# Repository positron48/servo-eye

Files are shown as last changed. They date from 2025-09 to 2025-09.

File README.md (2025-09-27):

# Eye Controller — ESP8266 Web‑Controlled Dual Servo

Control two hobby servos (yaw and pitch) from a responsive web UI hosted directly on an ESP8266 (Wemos D1 Mini). The firmware embeds the UI, exposes a small HTTP API, and persists settings so the device comes back exactly as you left it after power cycles.

## Contents
- [Overview](#overview)
- [Features](#features)
- [Hardware](#hardware)
- [Mounting Options](#mounting-options)
- [Quickstart](#quickstart)
- [Build and flash](#build-and-flash)
- [Web UI](#web-ui)
- [HTTP API](#http-api)
- [Servo setup and calibration](#servo-setup-and-calibration)
- [Create custom animations](#create-custom-animations)
- [Troubleshooting](#troubleshooting)
- [Technical details](#technical-details)
- [Build system (HTML → C++)](#build-system-html--c)
- [Project structure](#project-structure)
- [License](#license)
- [Support](#support)

## Overview
Eye Controller turns an ESP8266 into a self‑contained access point with a built‑in web interface to position two servos and play simple animations. It is ideal for animatronics like an eyeball that can look around with smooth motion.

<p align="center">
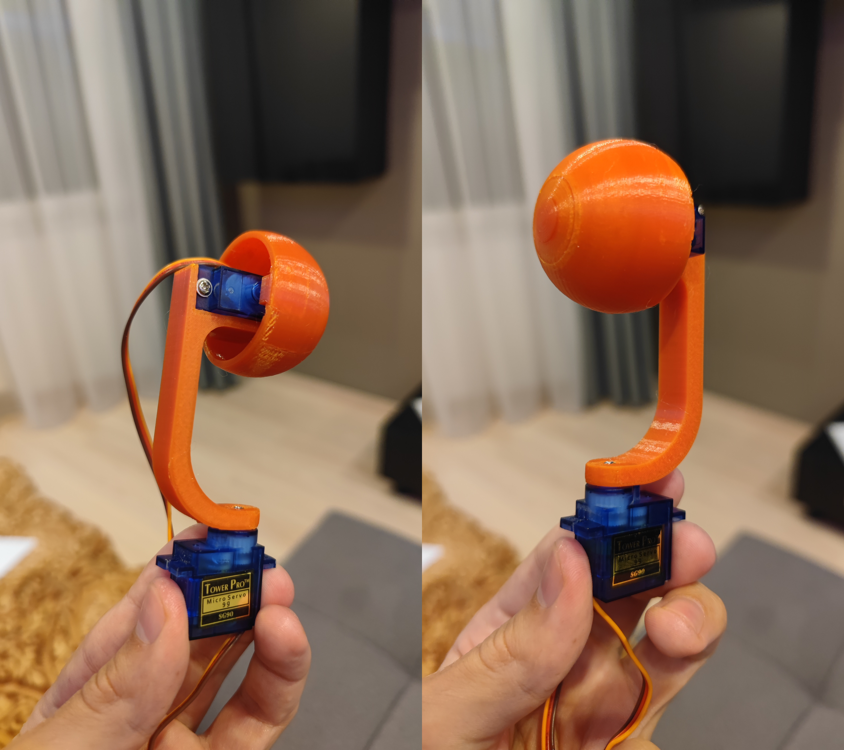
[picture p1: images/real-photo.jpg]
Real device photo
  
  <br/>
  <em>Real build of the Eye Controller in action</em>
  
</p>

## Features
- Wi‑Fi access point with a built‑in, responsive web UI
- Real‑time control for yaw and pitch
- Preset animations with adjustable speed and looping
- Settings saved to EEPROM and restored on boot
- HTML UI embedded directly in firmware (no external files required)
- Automatic HTML → C++ compilation during build

## Hardware
Target: ESP8266 (Wemos D1 Mini) + two 5V hobby servos (e.g., SG90).

<p align="center">
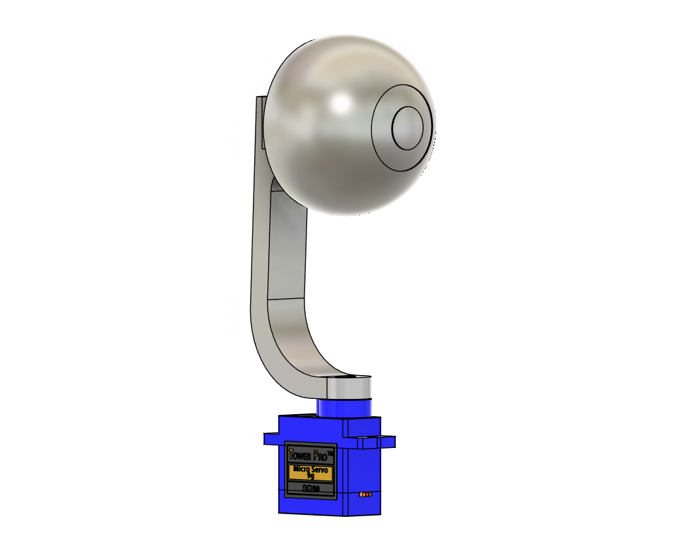
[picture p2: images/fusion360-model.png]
Fusion 360 model of the assembly
  
  <br/>
  <em>Fusion 360 model of the mechanical assembly</em>
</p>

Default connections:

```
ESP8266 (Wemos D1 Mini)    →    Servo
D1 (GPIO5)                  →    Yaw Servo signal
D2 (GPIO4)                  →    Pitch Servo signal
5V                          →    Servo power (+)
GND                         →    Shared ground
```

Recommendations:
- Power servos from a dedicated 5V source (≥2A) and tie GND with ESP8266
- Do not power servos from 3.3V pins
- Alternative pins are possible; see `ServoController.h`.

### Alternative pins
If D1 and D2 are occupied, update constants in `ServoController.h`:

```cpp
static const int YAW_PIN = D5;    // GPIO14
static const int PITCH_PIN = D6;  // GPIO12
```

Other usable pins: D5 (GPIO14), D6 (GPIO12), D7 (GPIO13). Avoid D8 (GPIO15) because it is pulled low at boot.

## Mounting Options

The project includes 3D printable mounting arms and connectors for different installation scenarios:

<p align="center">
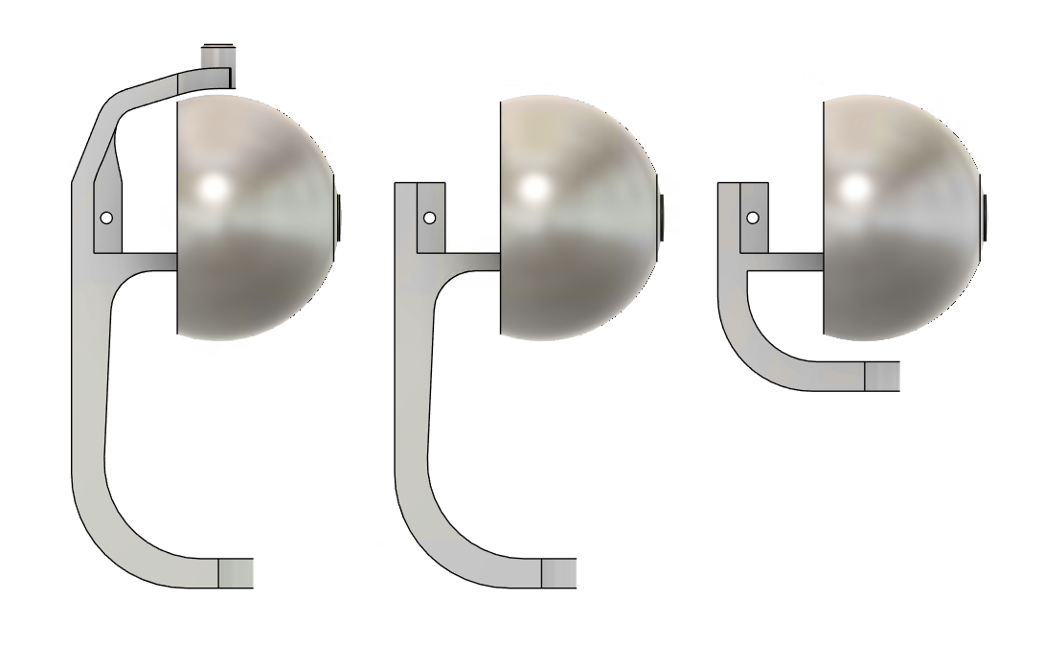
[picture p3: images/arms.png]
Mounting arm options
  
  <br/>
  <em>Three mounting arm options: long double-sided, long single-sided, and short single-sided</em>
</p>

<p align="center">
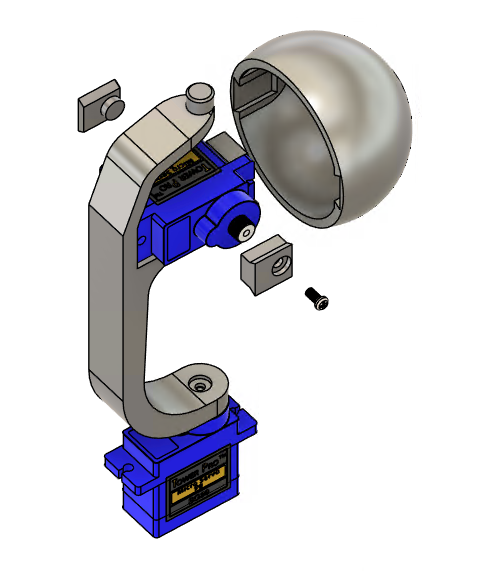
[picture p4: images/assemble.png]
Assembly example
  
  <br/>
  <em>Example assembly with mounting arms and connectors</em>
</p>

### Available STL Files
All 3D printable models are available in the [`model/`](model/) directory:

- **`arm.stl`** - Long double-sided mounting arm
- **`arm-long-one-side.stl`** - Long single-sided mounting arm  
- **`arm-short-one-side.stl`** - Short single-sided mounting arm
- **`eye.stl`** - Main eyeball housing
- **`connector1.stl`** - Servo connector #1
- **`connector2.stl`** - Servo connector #2

## Quickstart
Steps:
1) Wire two servos to D1 (yaw) and D2 (pitch), provide proper 5V power
2) Build and flash (PlatformIO):

```bash
pio run --target upload
```

3) Connect to Wi‑Fi AP: SSID `EyeController`, password `12345678`
4) Open the UI at `http://192.168.4.1` or `http://eye.local`

## Build and flash
Prerequisites:
- PlatformIO in VS Code (recommended)
- ESP8266 (Wemos D1 Mini)

Commands:

```bash
# Build and upload
pio run --target upload

# Optional: serial monitor
pio device monitor
```

The build integrates a pre‑step that compiles HTML from `web/` into C++ headers in `src/`.

## Web UI
The web UI offers:
- Canvas controller for intuitive look control with the mouse
- Yaw/Pitch sliders for precise positioning
- Preset animations with speed and loop options
- Built‑in CSV editor for custom animation sequences

<p align="center">
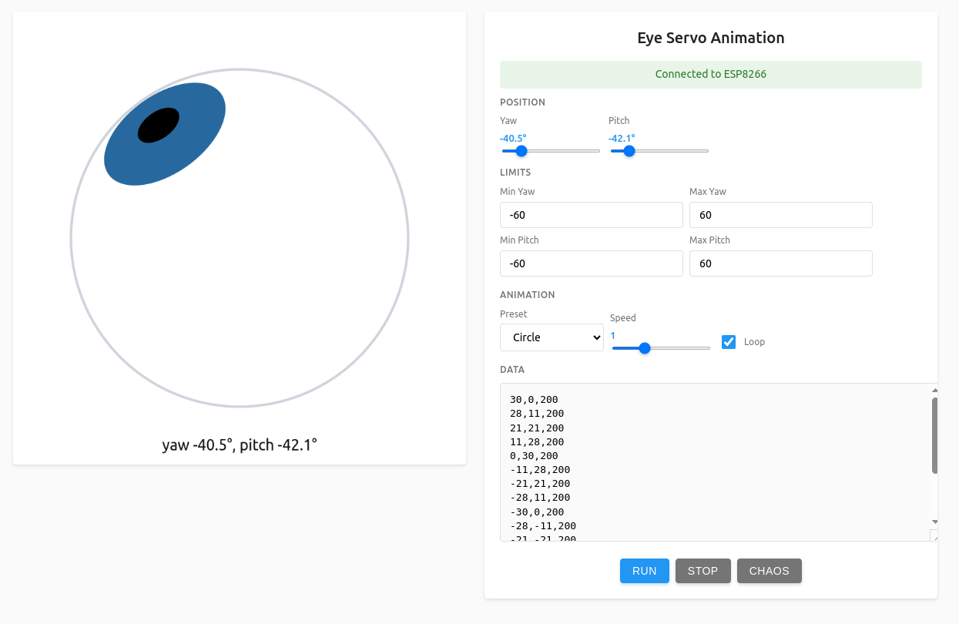
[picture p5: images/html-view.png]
Web UI screenshot
  
  <br/>
  <em>Web UI with canvas control, sliders, presets, and CSV editor</em>
</p>

## HTTP API
Base URL is the device root (`/`). All endpoints are plain HTTP.

### GET /api/position
Returns the current position and animation state.

```json
{
  "yaw": 0.0,
  "pitch": 0.0,
  "animationRunning": false,
  "currentPreset": "Center Sweep",
  "speed": 1.0,
  "loop": true
}
```

### POST /api/position
Set target servo position (degrees).

```
yaw=15.5&pitch=-10.0
```

### POST /api/animation
Start/stop animations. When starting, provide CSV data (see below).

```
action=start&data=-60,0,600\n-30,0,600\n0,0,600
action=stop
```

### POST /api/settings
Persist settings.

```
preset=Figure Eight&speed=1.5&loop=true
```

### GET /api/settings
Read saved settings.

## Servo setup and calibration
1) Move both servos to their neutral (center) position
2) Adjust horn/arm mounting to achieve the desired mechanical range
3) Use UI limits to keep motion within safe bounds

Recommended starting ranges:
- Yaw: −60° … +60°
- Pitch: −60° … +60°
- Animation speed: 0.5 … 2.0
- Typical servo: SG90 (180°)

## Create custom animations
Animations are defined in CSV as triples of `yaw,pitch,duration_ms` per line.

```
yaw,pitch,duration
-60,0,600
-30,0,600
0,0,600
30,0,600
60,0,600
0,0,600
```

Upload the CSV in the UI or send it with `/api/animation` when `action=start`.

## Troubleshooting
Servos do not move:
- Verify 5V power to servos
- Check signal wires on D1/D2
- Confirm UI limits are not restricting movement

Cannot connect to Wi‑Fi:
- Look for AP `EyeController` (password `12345678`)
- Connect directly to `192.168.4.1` if mDNS is unavailable

UI does not load:
- Clear browser cache or try another browser
- Ensure you are connected to the device AP

## Technical details
Libraries:
- ESPAsyncWebServer (HTTP server)
- ArduinoJson (JSON processing)
- Servo (servo control)
- ESP8266mDNS (mDNS `.local` support)

Resource usage (typical):
- Flash: ~400 KB
- RAM: ~30 KB
- EEPROM: ~512 bytes for settings

Performance (typical):
- Servo update rate: ~50 Hz
- UI latency: <100 ms
- Up to ~50 animation frames

## Build system (HTML → C++)
During `pio run` the HTML from `web/` is converted to a C++ header (e.g., `src/ui_html.h`) via the tools in `tools/`. The firmware then serves the embedded HTML and decodes it at runtime.

## Project structure
```
firmware/
├── web/                    HTML sources (UI)
├── tools/                  Build tools (HTML → C++)
├── src/                    Firmware sources (C++)
│   └── ui_html.h           Auto‑generated header
├── images/                 Documentation images
├── model/                  STL files for 3D printing
├── platformio.ini          PlatformIO configuration
└── *.md                    Documentation
```

## License
MIT License — free for personal and commercial use.

## OTA Updates
The firmware supports Over-The-Air (OTA) updates for wireless firmware updates.

### Quick OTA Commands
```bash
# USB upload (first time or when OTA fails)
pio run -e d1_mini -t upload

# OTA upload (wireless)
pio run -e d1_mini_ota -t upload
```

### OTA Configuration
- **Hostname**: `eye.local`
- **Port**: `8266`
- **Password**: `12345678`
- **WiFi Network**: `EyeController`

### WiFi Configuration
The device supports both WiFi client and Access Point modes:

- **Access Point Mode**: Default mode, creates "EyeController" network (password: 12345678)
- **WiFi Client Mode**: Connect to your home WiFi network via web interface
- **Auto Fallback**: If WiFi connection fails, automatically switches to AP mode

### WiFi Setup via Web Interface
1. Connect to "EyeController" network (password: 12345678)
2. Open web interface at `http://eye.local` or `http://192.168.4.1`
3. Go to "System Information" → "WiFi Settings"
4. Enable "Use WiFi Connection" and enter your network credentials
5. Click "Save WiFi Settings" - device will restart and connect to your network

### Troubleshooting OTA
- Ensure you're connected to "EyeController" WiFi network (or your configured network)
- If `eye.local` doesn't work, try IP address: `192.168.4.1` (AP mode) or your network IP
- Check serial monitor for OTA status messages
- Use USB upload if OTA fails

## Support
If you run into issues:
1) Check hardware connections and power
2) Verify settings and serial logs (`pio device monitor`)
3) Open an issue in the repository with details

More exclusive content and real-time updates in my [Telegram channel](https://t.me/positroidlive)

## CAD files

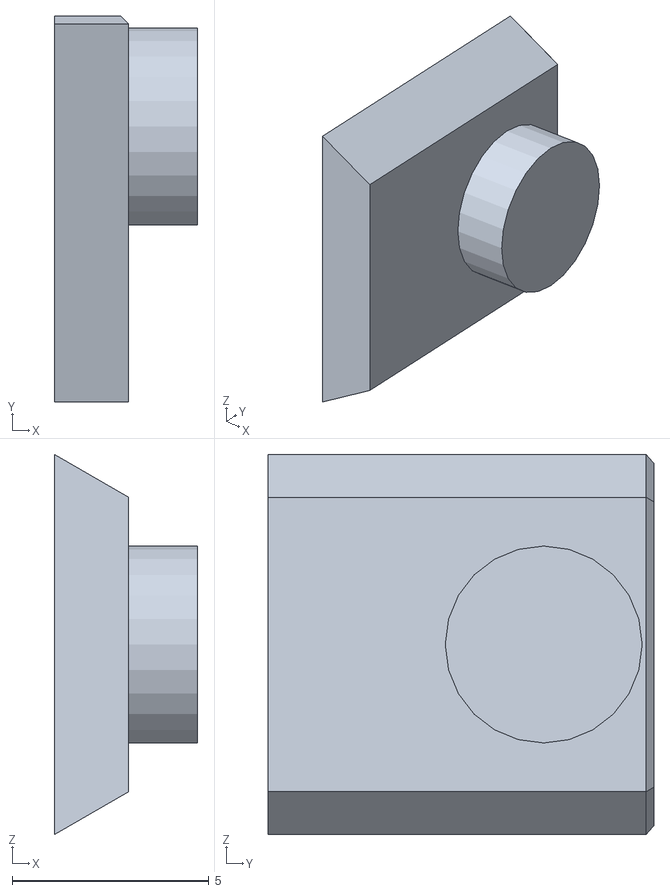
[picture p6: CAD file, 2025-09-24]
model/connector1.stl
3.64 x 9.80 x 9.65

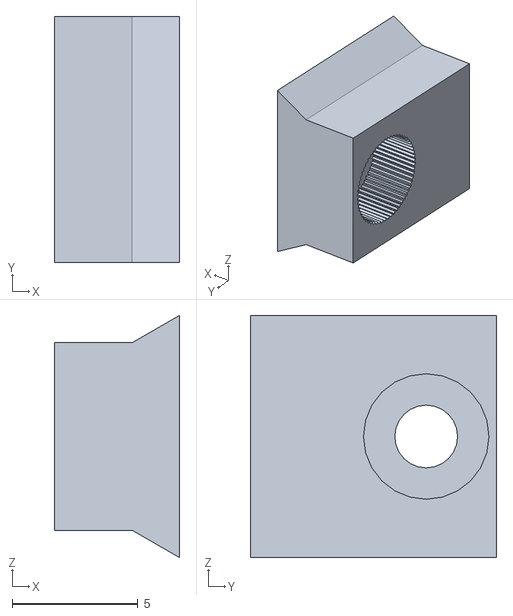
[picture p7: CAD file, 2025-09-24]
model/connector2.stl
4.99 x 9.80 x 9.65

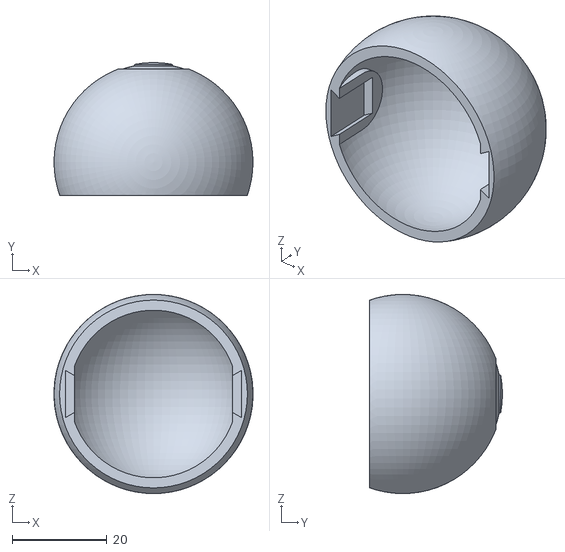
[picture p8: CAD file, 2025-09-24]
model/eye.stl
42.0 x 28.0 x 42.0

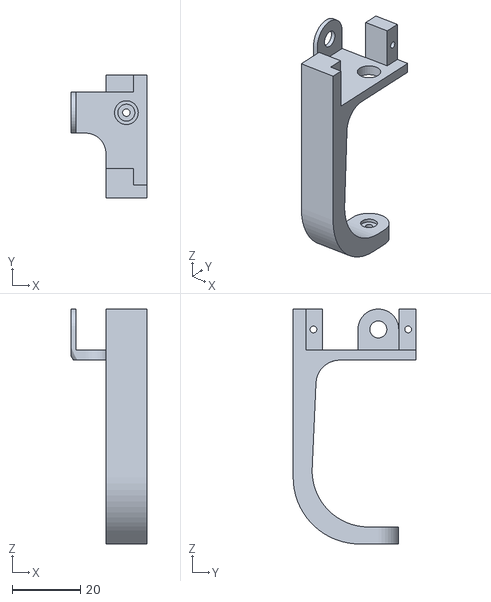
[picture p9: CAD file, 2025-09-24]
model/arm-long-one-side.stl
22.2 x 36.0 x 69.0

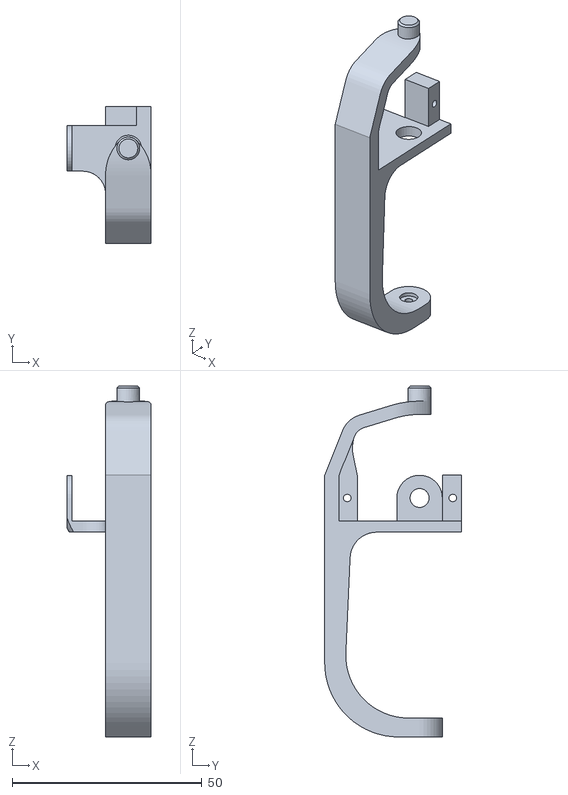
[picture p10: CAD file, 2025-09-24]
model/arm.stl
22.2 x 36.0 x 92.5

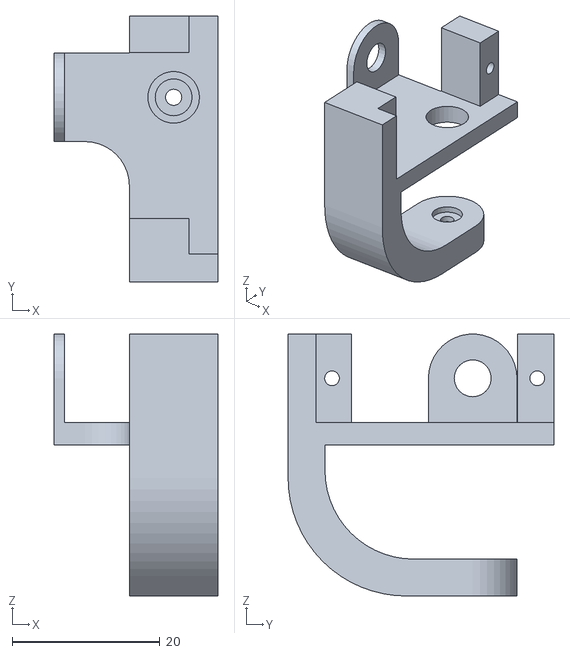
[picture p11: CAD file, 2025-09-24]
model/arm-short-one-side.stl
22.2 x 36.0 x 35.5

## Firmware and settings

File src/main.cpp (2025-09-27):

#include <Arduino.h>
#include <ESP8266WiFi.h>
#include <ESP8266WebServer.h>
#include <ArduinoJson.h>
#include <EEPROM.h>
#include <ESP8266mDNS.h>
#include <Servo.h>
#include <ArduinoOTA.h>
#include "ServoController.h"
#include "SettingsManager.h"
#include "WebServer.h"

// WiFi AP settings
const char* apSSID = "EyeController";
const char* apPassword = "12345678";

// WiFi connection state
bool wifiConnected = false;
bool apModeActive = false;
unsigned long wifiConnectStartTime = 0;
const unsigned long WIFI_CONNECT_TIMEOUT = 10000; // 10 seconds

// Web server
ESP8266WebServer server(80);
WebServer webServer(&server);

// Servo controller
ServoController servoController;

// Settings manager
SettingsManager settingsManager;

// Current state
struct EyeState {
  float yaw = 0.0;
  float pitch = 0.0;
  bool animationRunning = false;
  String currentPreset = "Center Sweep";
  float speed = 1.0;
  bool loop = true;
} eyeState;

// Forward declarations
void setupWiFi();
void startAPMode();
void checkWiFiConnection();

// OTA setup function
void setupOTA() {
  ArduinoOTA.setHostname("eye");
  ArduinoOTA.setPassword("12345678"); // Same as WiFi password
  
  ArduinoOTA.onStart([]() {
    String type = (ArduinoOTA.getCommand() == U_FLASH) ? "sketch" : "filesystem";
    Serial.println("Start updating " + type);
  });
  
  ArduinoOTA.onEnd([]() {
    Serial.println("\nEnd");
  });
  
  ArduinoOTA.onProgress([](unsigned int progress, unsigned int total) {
    Serial.printf("Progress: %u%%\r", (progress / (total / 100)));
  });
  
  ArduinoOTA.onError([](ota_error_t error) {
    Serial.printf("Error[%u]: ", error);
    if (error == OTA_AUTH_ERROR) Serial.println("Auth Failed");
    else if (error == OTA_BEGIN_ERROR) Serial.println("Begin Failed");
    else if (error == OTA_CONNECT_ERROR) Serial.println("Connect Failed");
    else if (error == OTA_RECEIVE_ERROR) Serial.println("Receive Failed");
    else if (error == OTA_END_ERROR) Serial.println("End Failed");
  });
  
  ArduinoOTA.begin();
  Serial.println("OTA Ready");
  Serial.print("OTA Hostname: ");
  Serial.println(ArduinoOTA.getHostname());
  Serial.println("OTA Port: 8266");
}

void setupWiFi() {
  const EyeSettings& settings = settingsManager.getSettings();
  
  if (settings.useWiFi && settings.wifiSSID.length() > 0) {
    Serial.println("Attempting to connect to WiFi: " + settings.wifiSSID);
    WiFi.mode(WIFI_STA);
    WiFi.begin(settings.wifiSSID.c_str(), settings.wifiPassword.c_str());
    wifiConnectStartTime = millis();
    wifiConnected = false;
    apModeActive = false;
  } else {
    Serial.println("No WiFi configured, starting AP mode");
    startAPMode();
  }
}

void startAPMode() {
  Serial.println("Starting Access Point mode");
  WiFi.mode(WIFI_AP);
  WiFi.softAP(apSSID, apPassword);
  IPAddress IP = WiFi.softAPIP();
  Serial.print("AP IP address: ");
  Serial.println(IP);
  apModeActive = true;
  wifiConnected = false;
}

void checkWiFiConnection() {
  if (apModeActive) return; // Already in AP mode
  
  if (!wifiConnected) {
    if (WiFi.status() == WL_CONNECTED) {
      wifiConnected = true;
      Serial.println("WiFi connected!");
      Serial.print("IP address: ");
      Serial.println(WiFi.localIP());
    } else if (millis() - wifiConnectStartTime > WIFI_CONNECT_TIMEOUT) {
      Serial.println("WiFi connection timeout, switching to AP mode");
      startAPMode();
    }
  }
}

void setup() {
  Serial.begin(115200);
  Serial.println("Starting Eye Controller...");

  // Initialize EEPROM
  EEPROM.begin(512);
  
  // Initialize servo controller
  servoController.begin();
  
  // Load saved settings
  settingsManager.loadSettings();
  
  // Apply loaded settings to eye state
  const EyeSettings& settings = settingsManager.getSettings();
  eyeState.yaw = settings.yaw;
  eyeState.pitch = settings.pitch;
  eyeState.currentPreset = settings.preset;
  eyeState.speed = settings.speed;
  eyeState.loop = settings.loop;
  
  // Setup WiFi
  setupWiFi();

  // Setup mDNS for eye.local
  if (MDNS.begin("eye")) {
    Serial.println("mDNS responder started");
  }

  // Setup OTA
  setupOTA();

  // Setup web server routes
  webServer.setupRoutes();
  
  // Start server
  server.begin();
  
  Serial.println("Eye Controller ready!");
}

void loop() {
  // Check WiFi connection
  checkWiFiConnection();
  
  // Handle OTA updates
  ArduinoOTA.handle();
  
  // Update servo controller
  servoController.update();
  
  // Handle web server
  server.handleClient();
  
  // Handle mDNS
  MDNS.update();
  
  delay(10);
}

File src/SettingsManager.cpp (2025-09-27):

#include "SettingsManager.h"

SettingsManager::SettingsManager() {
  // Initialize default settings
  settings.preset = "Center Sweep";
  settings.speed = 1.0;
  settings.loop = true;
  settings.yaw = 0.0;
  settings.pitch = 0.0;
  settings.minYaw = -60.0;
  settings.maxYaw = 60.0;
  settings.minPitch = -60.0;
  settings.maxPitch = 60.0;
  // WiFi settings defaults
  settings.wifiSSID = "";
  settings.wifiPassword = "";
  settings.useWiFi = false;
}

void SettingsManager::loadSettings() {
  // Check magic number
  int magic = 0;
  EEPROM.get(SETTINGS_ADDRESS, magic);
  
  if (magic != MAGIC_NUMBER) {
    Serial.println("No valid settings found, using defaults");
    return;
  }
  
  int address = SETTINGS_ADDRESS + sizeof(int);
  
  // Load settings
  settings.preset = readStringFromEEPROM(address, 50);
  address += 50;
  
  settings.speed = readFloatFromEEPROM(address);
  address += sizeof(float);
  
  settings.loop = readBoolFromEEPROM(address);
  address += sizeof(bool);
  
  settings.yaw = readFloatFromEEPROM(address);
  address += sizeof(float);
  
  settings.pitch = readFloatFromEEPROM(address);
  address += sizeof(float);
  
  settings.minYaw = readFloatFromEEPROM(address);
  address += sizeof(float);
  
  settings.maxYaw = readFloatFromEEPROM(address);
  address += sizeof(float);
  
  settings.minPitch = readFloatFromEEPROM(address);
  address += sizeof(float);
  
  settings.maxPitch = readFloatFromEEPROM(address);
  address += sizeof(float);
  
  // Load WiFi settings
  settings.wifiSSID = readStringFromEEPROM(address, 50);
  address += 50;
  
  settings.wifiPassword = readStringFromEEPROM(address, 50);
  address += 50;
  
  settings.useWiFi = readBoolFromEEPROM(address);
  
  Serial.println("Settings loaded from EEPROM");
  Serial.println("Preset: " + settings.preset);
  Serial.println("Speed: " + String(settings.speed));
  Serial.println("Loop: " + String(settings.loop));
  Serial.println("Position: Yaw=" + String(settings.yaw) + ", Pitch=" + String(settings.pitch));
  Serial.println("WiFi: " + String(settings.useWiFi ? "Enabled" : "Disabled"));
  if (settings.useWiFi) {
    Serial.println("WiFi SSID: " + settings.wifiSSID);
  }
}

void SettingsManager::saveSettings(const EyeSettings& newSettings) {
  settings = newSettings;
  saveSettings(settings.yaw, settings.pitch, settings.preset, settings.speed, settings.loop);
}

void SettingsManager::saveSettings(float yaw, float pitch, const String& preset, float speed, bool loop) {
  int address = SETTINGS_ADDRESS;
  
  // Write magic number
  EEPROM.put(address, MAGIC_NUMBER);
  address += sizeof(int);
  
  // Write settings
  writeStringToEEPROM(address, preset);
  address += 50;
  
  writeFloatToEEPROM(address, speed);
  address += sizeof(float);
  
  writeBoolToEEPROM(address, loop);
  address += sizeof(bool);
  
  writeFloatToEEPROM(address, yaw);
  address += sizeof(float);
  
  writeFloatToEEPROM(address, pitch);
  address += sizeof(float);
  
  writeFloatToEEPROM(address, settings.minYaw);
  address += sizeof(float);
  
  writeFloatToEEPROM(address, settings.maxYaw);
  address += sizeof(float);
  
  writeFloatToEEPROM(address, settings.minPitch);
  address += sizeof(float);
  
  writeFloatToEEPROM(address, settings.maxPitch);
  address += sizeof(float);
  
  // Save WiFi settings
  writeStringToEEPROM(address, settings.wifiSSID);
  address += 50;
  
  writeStringToEEPROM(address, settings.wifiPassword);
  address += 50;
  
  writeBoolToEEPROM(address, settings.useWiFi);
  
  EEPROM.commit();
  
  Serial.println("Settings saved to EEPROM");
}

void SettingsManager::writeStringToEEPROM(int address, const String& str) {
  int len = str.length();
  if (len > 49) len = 49; // Max 49 chars + null terminator
  
  for (int i = 0; i < len; i++) {
    EEPROM.write(address + i, str[i]);
  }
  EEPROM.write(address + len, '\0'); // Null terminator
}

String SettingsManager::readStringFromEEPROM(int address, int maxLength) {
  String result = "";
  
  for (int i = 0; i < maxLength - 1; i++) {
    char c = EEPROM.read(address + i);
    if (c == '\0') break;
    result += c;
  }
  
  return result;
}

void SettingsManager::writeFloatToEEPROM(int address, float value) {
  EEPROM.put(address, value);
}

float SettingsManager::readFloatFromEEPROM(int address) {
  float value;
  EEPROM.get(address, value);
  return value;
}

void SettingsManager::writeBoolToEEPROM(int address, bool value) {
  EEPROM.write(address, value ? 1 : 0);
}

bool SettingsManager::readBoolFromEEPROM(int address) {
  return EEPROM.read(address) != 0;
}
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

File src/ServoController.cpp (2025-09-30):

#include "ServoController.h"

ServoController::ServoController() 
  : currentYaw(0.0), currentPitch(0.0), animationRunning(false),
    animationFrames(nullptr), frameCount(0), currentFrame(0),
    lastMovementTime(0), servosDisabled(false), minYaw(-60.0), maxYaw(60.0), minPitch(-60.0), maxPitch(60.0) {
}

ServoController::~ServoController() {
  if (animationFrames) {
    delete[] animationFrames;
  }
}

void ServoController::begin() {
  yawServo.attach(YAW_PIN);
  pitchServo.attach(PITCH_PIN);
  
  // Set initial position (center)
  setPosition(0.0, 0.0);
  
  Serial.println("ServoController initialized");
}

void ServoController::update() {
  unsigned long currentTime = millis();
  
  // Check for servo timeout (disable servos after 200ms of no movement)
  // This works even during animation - if position doesn't change, servos will be disabled
  if (!servosDisabled && (currentTime - lastMovementTime) >= (unsigned long)SERVO_TIMEOUT_MS) {
    disableServos();
  }
  
  if (!animationRunning || !animationFrames || frameCount == 0) {
    return;
  }
  
  unsigned long elapsed = currentTime - frameStartTime;
  
  AnimationFrame& current = animationFrames[currentFrame];
  
  if (elapsed >= current.duration) {
    // Move to next frame
    currentFrame++;
    frameStartTime = currentTime;
    
    if (currentFrame >= frameCount) {
      // Animation finished, restart from beginning
      currentFrame = 0;
    }
    
    // Set position for new frame
    setPosition(current.yaw, current.pitch);
  } else {
    // Get previous frame for comparison
    AnimationFrame& prev = animationFrames[(currentFrame - 1 + frameCount) % frameCount];
    float progress = (float)elapsed / current.duration;
    
    // Check if current position is the same as previous (for hold points)
    bool isHoldPoint = (abs(current.yaw - prev.yaw) < 0.1f && abs(current.pitch - prev.pitch) < 0.1f);
    
    if (isHoldPoint) {
      // For hold points, just set the position directly (no interpolation)
      setPosition(current.yaw, current.pitch);
    } else {
      // For movement points, use interpolation from previous to current
      float interpolatedYaw = prev.yaw + (current.yaw - prev.yaw) * progress;
      float interpolatedPitch = prev.pitch + (current.pitch - prev.pitch) * progress;
      
      setPosition(interpolatedYaw, interpolatedPitch);
    }
  }
}

void ServoController::setPosition(float yaw, float pitch) {
  // Clamp values to limits
  float newYaw = constrain(yaw, minYaw, maxYaw);
  float newPitch = constrain(pitch, minPitch, maxPitch);
  
  // Only update if position actually changed (more than 0.1 degrees)
  if (abs(newYaw - currentYaw) > 0.1f || abs(newPitch - currentPitch) > 0.1f) {
    currentYaw = newYaw;
    currentPitch = newPitch;
    
    // Update last movement time and mark servos as active
    lastMovementTime = millis();
    servosDisabled = false;
    
    updateServos();
  }
}

void ServoController::setLimits(float minYaw, float maxYaw, float minPitch, float maxPitch) {
  this->minYaw = minYaw;
  this->maxYaw = maxYaw;
  this->minPitch = minPitch;
  this->maxPitch = maxPitch;
  
  // Re-constrain current position
  setPosition(currentYaw, currentPitch);
}

void ServoController::disableServos() {
  // Detach servos to remove power
  yawServo.detach();
  pitchServo.detach();
  
  servosDisabled = true;
  Serial.println("Servos disabled (power removed)");
}

void ServoController::startAnimation(const String& data) {
  stopAnimation();
  parseAnimationData(data);
  
  if (frameCount > 0 && animationFrames) {
    animationRunning = true;
    currentFrame = 0;
    frameStartTime = millis();
    
    // Set initial position
    setPosition(animationFrames[0].yaw, animationFrames[0].pitch);
    
    Serial.println("Animation started with " + String(frameCount) + " frames");
  }
}

void ServoController::stopAnimation() {
  animationRunning = false;
  
  if (animationFrames) {
    delete[] animationFrames;
    animationFrames = nullptr;
  }
  
  frameCount = 0;
  currentFrame = 0;
  
  Serial.println("Animation stopped");
}

float ServoController::mapAngleToPWM(float angle) {
  // Map angle to PWM value (500-2500 microseconds)
  // Используем полный физический диапазон сервы, не ограничения
  float normalized = (angle - SERVO_ANGLE_MIN) / (SERVO_ANGLE_MAX - SERVO_ANGLE_MIN);
  return 500 + normalized * 2000; // 500-2500 microseconds
}

void ServoController::updateServos() {
  // Reattach servos if they were detached
  if (yawServo.attached() == 0U) {
    yawServo.attach(YAW_PIN);
  }
  if (pitchServo.attached() == 0U) {
    pitchServo.attach(PITCH_PIN);
  }
  
  // Mark servos as active if they were reattached
  if (servosDisabled && (yawServo.attached() != 0U || pitchServo.attached() != 0U)) {
    servosDisabled = false;
  }
  
  // Convert angles to PWM values
  // Используем полный физический диапазон сервы, не ограничения
  float yawPWM = mapAngleToPWM(currentYaw);
  // Invert pitch servo (просто инвертируем угол)
  float pitchPWM = mapAngleToPWM(-currentPitch);
  
  // Write to servos
  yawServo.writeMicroseconds((int)yawPWM);
  pitchServo.writeMicroseconds((int)pitchPWM);
  
  Serial.println("Position: Yaw=" + String(currentYaw, 1) + "°, Pitch=" + String(currentPitch, 1) + "°");
}

void ServoController::parseAnimationData(const String& data) {
  // Clear existing animation
  if (animationFrames) {
    delete[] animationFrames;
    animationFrames = nullptr;
  }
  
  // Count lines
  frameCount = 0;
  int start = 0;
  while (start < data.length()) {
    int end = data.indexOf('\n', start);
    if (end == -1) end = data.length();
    
    String line = data.substring(start, end);
    line.trim();
    
    if (line.length() > 0) {
      frameCount++;
    }
    
    start = end + 1;
  }
  
  if (frameCount == 0) {
    return;
  }
  
  // Allocate memory for frames
  animationFrames = new AnimationFrame[frameCount];
  
  // Parse lines
  int frameIndex = 0;
  start = 0;
  while (start < data.length() && frameIndex < frameCount) {
    int end = data.indexOf('\n', start);
    if (end == -1) end = data.length();
    
    String line = data.substring(start, end);
    line.trim();
    
    if (line.length() > 0) {
      // Parse CSV format: yaw,pitch,duration
      int comma1 = line.indexOf(',');
      int comma2 = line.indexOf(',', comma1 + 1);
      
      if (comma1 > 0 && comma2 > comma1) {
        animationFrames[frameIndex].yaw = line.substring(0, comma1).toFloat();
        animationFrames[frameIndex].pitch = line.substring(comma1 + 1, comma2).toFloat();
        animationFrames[frameIndex].duration = line.substring(comma2 + 1).toInt();
        
        frameIndex++;
      }
    }
    
    start = end + 1;
  }
  
  frameCount = frameIndex;
  
  Serial.println("Parsed " + String(frameCount) + " animation frames");
}

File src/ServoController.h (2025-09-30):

#ifndef SERVO_CONTROLLER_H
#define SERVO_CONTROLLER_H

#include <Arduino.h>
#include <Servo.h>

struct AnimationFrame {
  float yaw;
  float pitch;
  int duration; // milliseconds
};

class ServoController {
private:
  Servo yawServo;
  Servo pitchServo;
  
  // Pin definitions
  static const int YAW_PIN = D2;
  static const int PITCH_PIN = D1;
  
  // Current position
  float currentYaw;
  float currentPitch;
  
  // Animation state
  bool animationRunning;
  AnimationFrame* animationFrames;
  int frameCount;
  int currentFrame;
  unsigned long frameStartTime;
  
  // Servo timeout management
  unsigned long lastMovementTime;
  static const unsigned long SERVO_TIMEOUT_MS = 200; // Reduced from 300ms to 200ms
  bool servosDisabled;
  
  // Limits (для валидации на фронтенде)
  float minYaw;
  float maxYaw;
  float minPitch;
  float maxPitch;
  
  // Physical servo range (полный диапазон для маппинга на PWM)
  static constexpr float SERVO_ANGLE_MIN = -60.0f;
  static constexpr float SERVO_ANGLE_MAX = 60.0f;
  
  // Helper functions
  float mapAngleToPWM(float angle);
  void updateServos();
  void parseAnimationData(const String& data);
  
public:
  ServoController();
  ~ServoController();
  
  void begin();
  void update();
  
  void setPosition(float yaw, float pitch);
  void setLimits(float minYaw, float maxYaw, float minPitch, float maxPitch);
  void disableServos();
  
  void startAnimation(const String& data);
  void stopAnimation();
  
  float getCurrentYaw() const { return currentYaw; }
  float getCurrentPitch() const { return currentPitch; }
  bool isAnimationRunning() const { return animationRunning; }
  
  // Геттеры для ограничений (используются на фронтенде)
  float getMinYaw() const { return minYaw; }
  float getMaxYaw() const { return maxYaw; }
  float getMinPitch() const { return minPitch; }
  float getMaxPitch() const { return maxPitch; }
};

#endif

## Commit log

2025-09-24 add stl models
    [arm-long-one-side.stl, arm-short-one-side.stl, arm.stl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]
2025-09-30 fix servo limits
